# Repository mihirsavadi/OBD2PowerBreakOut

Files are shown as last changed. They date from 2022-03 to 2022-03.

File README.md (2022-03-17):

# OBD2PowerBreakOut Board

  

A simple breakout board that uses inputs from an OBD2 pigtail, and breaks them out with a series of XT30PW connectors.
Each power channel is fuse protected with standard automotive fuses, includes an LED to for easy FUSE integrity
checking, and selectability between 'always on' or 'only on after ignition'. The aforementioned selectability is
accomplished by jumping two pins -- this is self-descriptive on the pcb.

The PIN that connects to power only upon ignition differs between brands. This pin is called the ACC pin. You will have
to research and find out which PIN corresponds to your specific ACC pin. You can also use a multimeter to test and find
out. Below is the standard pinout for an OBD2 connector -- the ACC pin can only exist on any one of the vendor specific
pins. For my 2004 Land Rover Discovery II, the ACC pin is located at pin ???.

The color codes in the following pin-out are in reference to the pigtail found here --
https://www.amazon.com/dp/B07F16GPMB?ref=ppx_yo2_dt_b_product_details&th=1 (iKKEGOL 16 Pin J1962 OBD2 OBD-II Male Connector to Open Plug Wire, OBD Diagnostic Extension Cable Pigtail for DIY (60cm 24" inch, 2ft))
1. **Black** Vendor  
2. **Brown** - J1850 Bus+
3. **Red** - Vendor
4. **Orange** - chassis ground
5. **Yellow** - signal ground
6. **Green** - CAN high
7. **Blue** - K-line
8. **Purple** - Vendor
9. **Gray** - Vendor
10. **White-** J1850 BUS
11. **Pink** - Vendor
12. **Teal** - Vendor
13. **Black/White** - Vendor
14. **Brown/White** - CAN low
15. **Red/White** - K line low
16. **Green/White** - Battery

XT30 connectors are used in this board for easy jerry-rigging of accessories -- XT30's are easy to source, easy to
install, and reliable.

I permanently run an UltraGauge to monitor various information in real time, and as such needed more than just 1 OBD2
port in order to run the OBD2_PowerBreakOut board. I simply used a Y splitter like this one --
https://www.amazon.com/gp/product/B07K6MWQTB/ref=ppx_yo_dt_b_search_asin_title?ie=UTF8&psc=1.

Below are some screenshots of the rendering of the assembled board. I will include real-life photos once assembled.

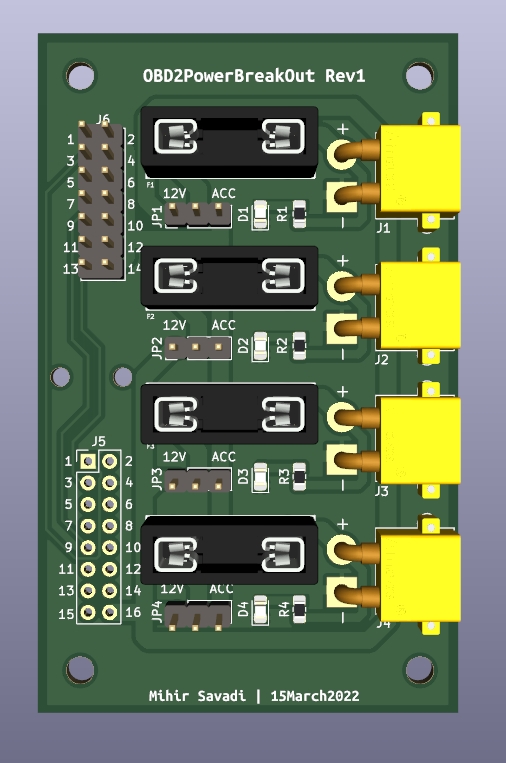
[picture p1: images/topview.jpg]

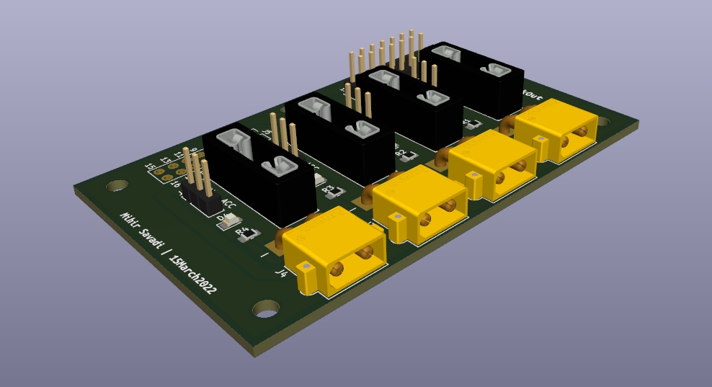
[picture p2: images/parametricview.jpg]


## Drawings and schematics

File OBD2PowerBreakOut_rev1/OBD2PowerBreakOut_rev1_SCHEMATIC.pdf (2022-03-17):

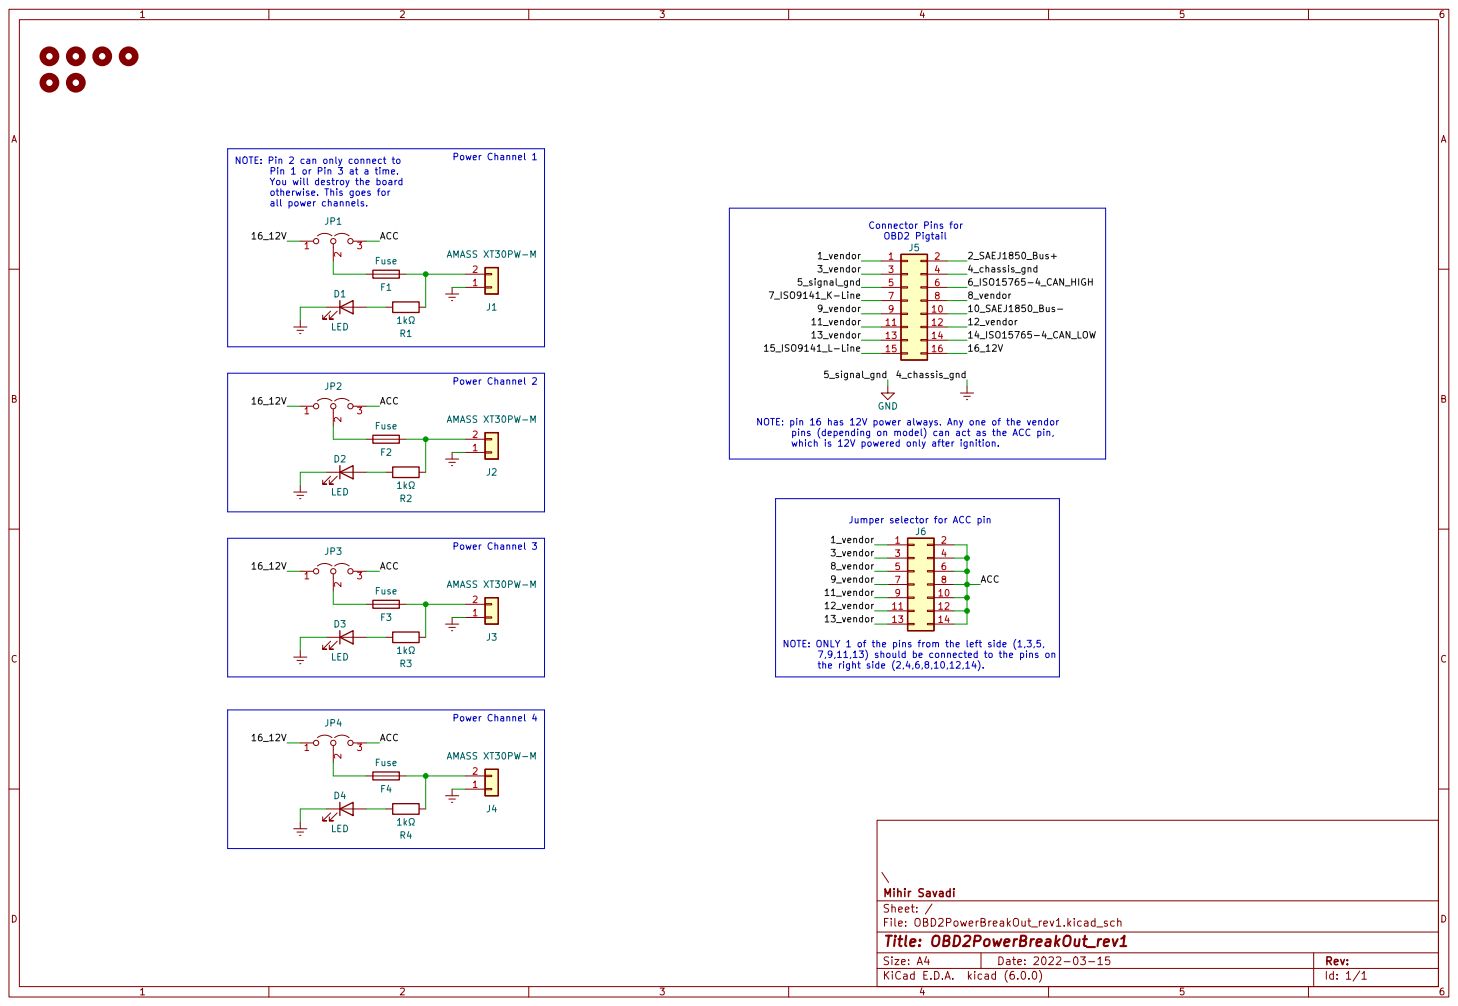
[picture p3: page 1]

Power Channel 2 Power Channel 4
J4 AMASS XT30PW-M 12

NOTE: Pin 2 can only connect to
Pin 1 or Pin 3 at a time.
You will destroy the board
otherwise. This goes for

NOTE: pin 16 has 12V power always. Any one of the vendor
pins (depending on model) can act as the ACC pin,
which is 12V powered only after ignition.

Jumper selector for ACC pin

File: OBD2PowerBreakOut_rev1.kicad_sch Sheet: / Mihir Savadi \ 12

7,9,11,13) should be connected to the pins on
the right side (2,4,6,8,10,12,14).

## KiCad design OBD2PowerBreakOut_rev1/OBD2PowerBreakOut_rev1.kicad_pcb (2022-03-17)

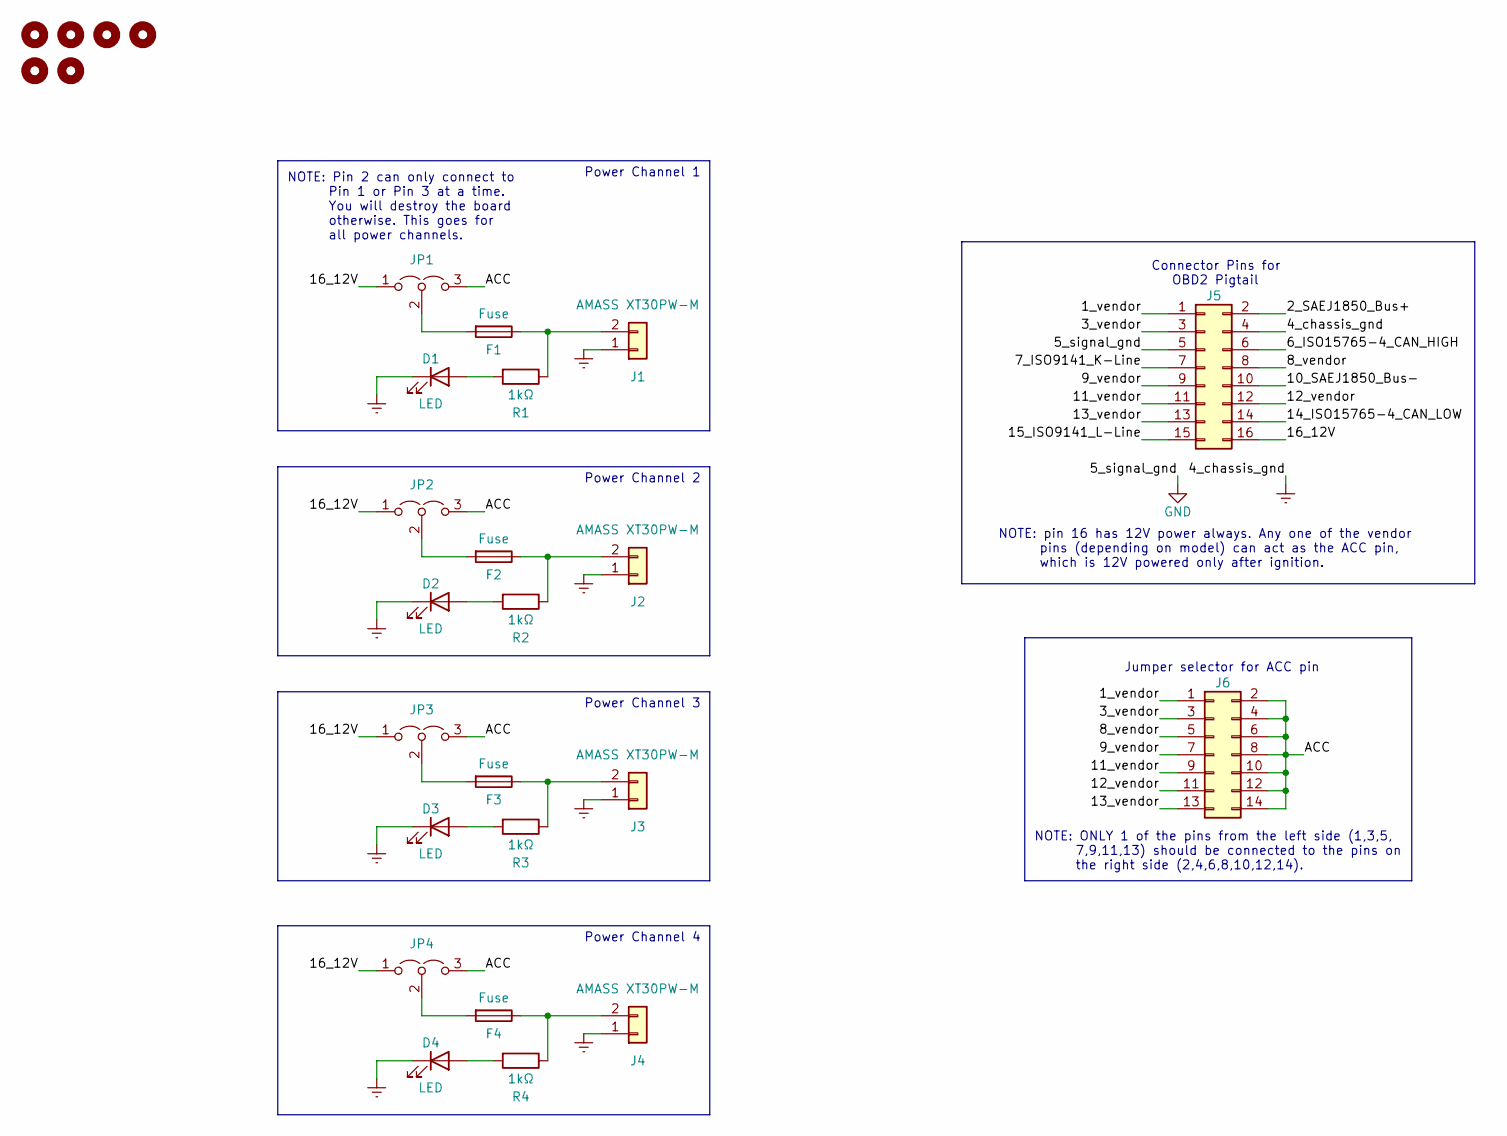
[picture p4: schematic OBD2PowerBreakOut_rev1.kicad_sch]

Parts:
D1, D2, D3, D4: LED; LED_0805_2012Metric_Pad1.15x1.40mm_HandSolder
F1, F2, F3, F4: Fuse; FuseHolder_Keystone_3557-2
H1, H3, H5, H6: M3 Mounting Hole; MountingHole_3.2mm_M3
H2, H4: M2 strain relief hole; MountingHole_2.2mm_M2
J1, J2, J3, J4: AMASS XT30PW-M; AMASS_XT30PW-M_1x02_P2.50mm_Horizontal
J5: Conn_02x08_Odd_Even; PinHeader_2x08_P2.54mm_Vertical
J6: Conn_02x07_Odd_Even; PinHeader_2x07_P2.54mm_Vertical
JP1, JP2, JP3, JP4: Jumper_3_Open; PinHeader_1x03_P2.54mm_Vertical
R1, R2, R3, R4: 1kΩ; R_0805_2012Metric_Pad1.20x1.40mm_HandSolder

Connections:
/1_vendor: J5.1, J6.1
/2_SAEJ1850_Bus+: J5.2
/3_vendor: J5.3, J6.3
/6_ISO15765-4_CAN_HIGH: J5.6
/7_ISO9141_K-Line: J5.7
/8_vendor: J5.8, J6.5
/9_vendor: J5.9, J6.7
/10_SAEJ1850_Bus-: J5.10
/11_vendor: J5.11, J6.9
/12_vendor: J5.12, J6.11
/13_vendor: J5.13, J6.13
/14_ISO15765-4_CAN_LOW: J5.14
/15_ISO9141_L-Line: J5.15
/16_12V: J5.16, JP1.1 (A), JP2.1 (A), JP3.1 (A), JP4.1 (A)
/ACC: J6.2, J6.4, J6.6, J6.8, J6.10, J6.12, J6.14, JP1.3 (B), JP2.3 (B), JP3.3 (B), JP4.3 (B)
Earth: D1.1 (K), D2.1 (K), D3.1 (K), D4.1 (K), J1.1, J2.1, J3.1, J4.1, J5.4
GND: J5.5
unnamed: D1.2 (A), R1.2
unnamed: D2.2 (A), R2.2
unnamed: D3.2 (A), R3.2
unnamed: D4.2 (A), R4.2
unnamed: F1.1, J1.2, R1.1
unnamed: F1.2, JP1.2 (C)
unnamed: F2.1, J2.2, R2.1
unnamed: F2.2, JP2.2 (C)
unnamed: F3.1, J3.2, R3.1
unnamed: F3.2, JP3.2 (C)
unnamed: F4.1, J4.2, R4.1
unnamed: F4.2, JP4.2 (C)

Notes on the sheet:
Power Channel 1
Power Channel 3
Jumper selector for ACC pin
Power Channel 2
NOTE: ONLY 1 of the pins from the left side (1,3,5, 7,9,11,13) should be connected to the pins on the right side (2,4,6,8,10,12,14).
Connector Pins for OBD2 Pigtail
NOTE: Pin 2 can only connect to Pin 1 or Pin 3 at a time. You will destroy the board otherwise. This goes for all power channels.
NOTE: pin 16 has 12V power always. Any one of the vendor pins (depending on model) can act as the ACC pin, which is 12V powered only after ignition.
Power Channel 4

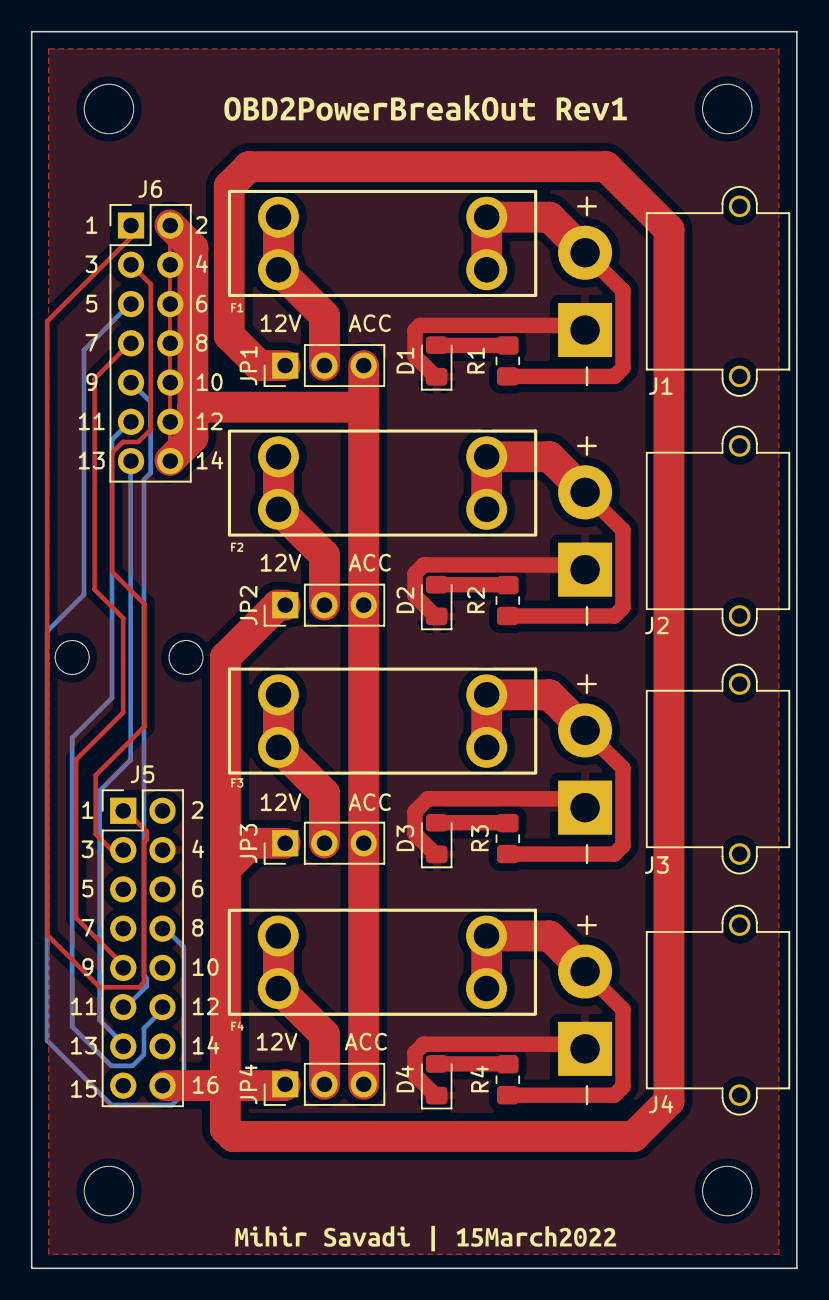
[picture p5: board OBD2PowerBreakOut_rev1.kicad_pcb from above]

Board: 4 copper layers, 49.5 x 80.0 mm, 30 parts (0 on the bottom side), 22 nets.

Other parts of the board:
kibuzzard-6231480B: G***; kibuzzard-6231480B
kibuzzard-6231482B: G***; kibuzzard-6231482B

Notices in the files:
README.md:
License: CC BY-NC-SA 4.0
